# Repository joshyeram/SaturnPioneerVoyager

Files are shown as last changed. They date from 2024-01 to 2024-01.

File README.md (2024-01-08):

# Saturn with Pioneer and Voyager

link to the build video: https://www.youtube.com/watch?v=A1N8exJrTmQ

# Saturn
pioneer
With this keyboard, I wanted to experiment with the possibility of hot-swappable keyboards. In the current state of using machine sockets and pins, no one dares to hot-swap. And I wanted to fix that and come up with a universal microcontroller daughter board that you can simply swap around.

# Pioneer
pioneer
Pioneer is a simple daughterboard that supports a pro-micro-like microcontroller and a simple switch (reset). You can use qmk to program it.

# Voyager
voyager
Voyager is a complicated daughterboard that supports a pro-micro-like microcontroller, either oled or nice!view, a battery, and two switches (reset and power). Because of this, it is very thick to support all the hardware. In this case, I decided to use a Supermini for cost reasons. However, a genuine nice!nano should work as well. For programming, zmk was used for Bluetooth. 

# PCB
pcb
All you need is one pcb for all the boards. This is because I designed the daughter boards to be in the corners of the board to save manufacturing costs. This is at the cost of needing to score and snap off each board.
pcb
pcb
The reason why this works is because all the connections are standardized
pcb
Also, I think I got really lucky with the auditor not checking the thin mouse bite. so you may need to increase the tab if they do not except it.

# Firmware
I have already compiled and posted the .hex (qmk) and build.yaml(zmk) in the firmware folder. However, if you would like to make it your own, I have posted the full source code of what I used as well. (There may be some refactoring issues but I think I got most of them. Let me know if there is anything to fix)

# Parts
The most important part of the whole build was the DB25 connectors. I had to edit the existing DB25 footprint to fit my DB25 pins. So, you might have to as well.
Here is the list of parts I used
- pcb
- db25 connectors from amazon
- promicro 
- nice!nano clone
- nice!view from typeractive.xyz (they are great btw)
-  holy panda clones
- silent honey peaches
- 3 pin switches
- 1n4148 diodes
- uv resin
- some wire for cs pin
- keycaps (cerakeys w)

# anything else
please ask me anything if you guys want to! it is joshyeram on most platforms.

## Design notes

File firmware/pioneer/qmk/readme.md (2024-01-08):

# keyboard/pioneer

keyboard/pioneer

*A short description of the keyboard/project*

* Keyboard Maintainer: [joshyeram](https://github.com/joshyeram)
* Hardware Supported: *The PCBs, controllers supported*
* Hardware Availability: *Links to where you can find this hardware*

Make example for this keyboard (after setting up your build environment):

    make keyboard/pioneer:default

Flashing example for this keyboard:

    make keyboard/pioneer:default:flash

See the [build environment setup](https://docs.qmk.fm/#/getting_started_build_tools) and the [make instructions](https://docs.qmk.fm/#/getting_started_make_guide) for more information. Brand new to QMK? Start with our [Complete Newbs Guide](https://docs.qmk.fm/#/newbs).

## Bootloader

Enter the bootloader in 3 ways:

* **Bootmagic reset**: Hold down the key at (0,0) in the matrix (usually the top left key or Escape) and plug in the keyboard
* **Physical reset button**: Briefly press the button on the back of the PCB - some may have pads you must short instead
* **Keycode in layout**: Press the key mapped to `QK_BOOT` if it is available

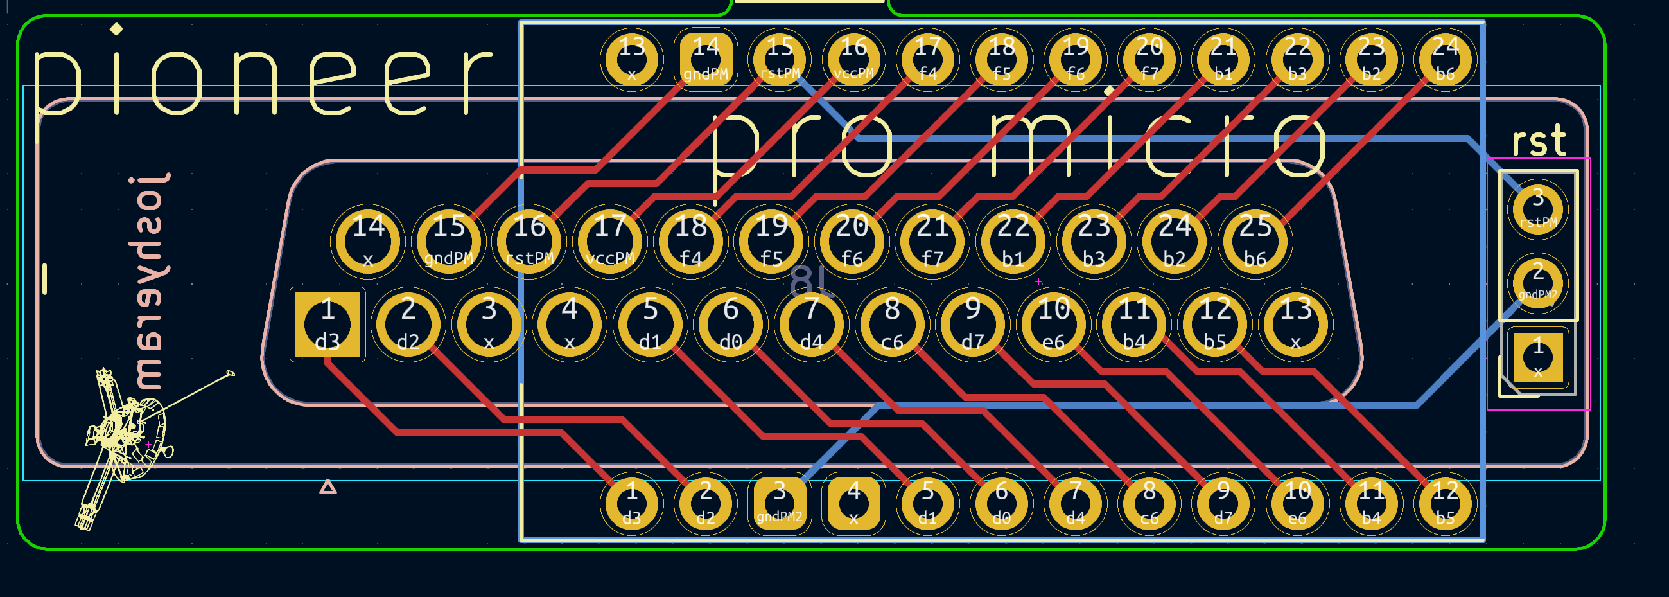
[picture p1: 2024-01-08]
overviewPngs/pioneerQuickOverview.PNG

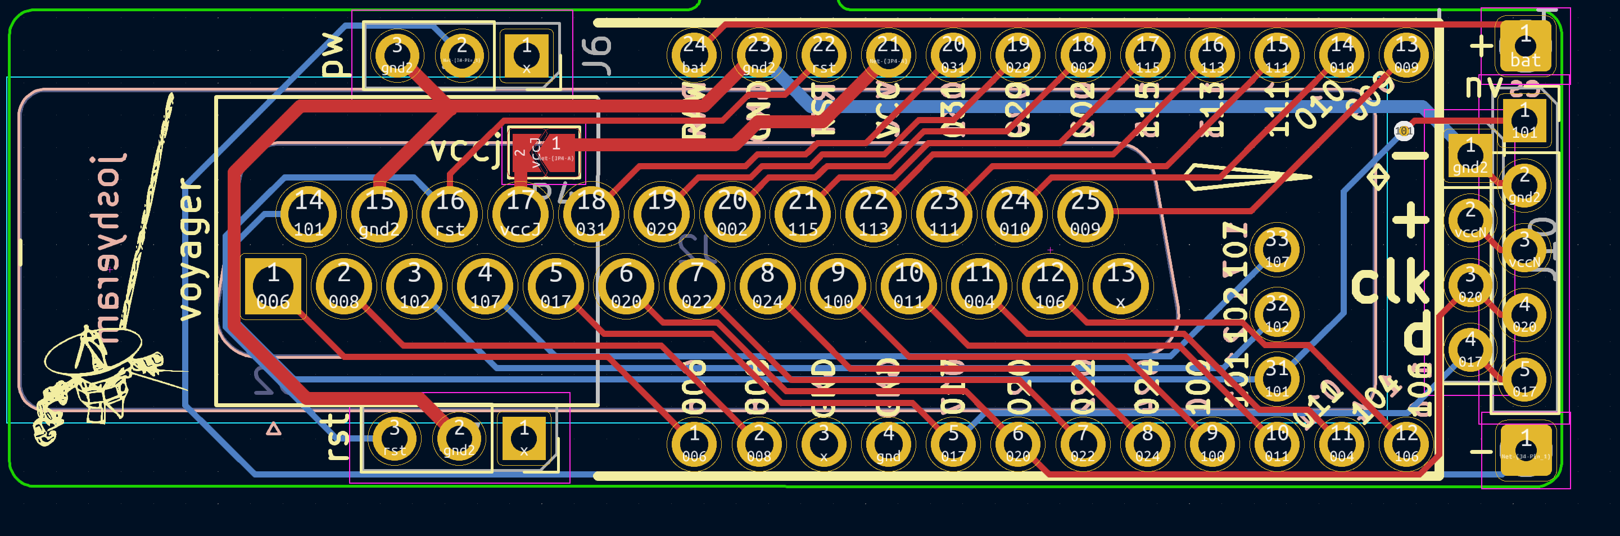
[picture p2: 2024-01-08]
overviewPngs/voyagerQuickOverview.PNG

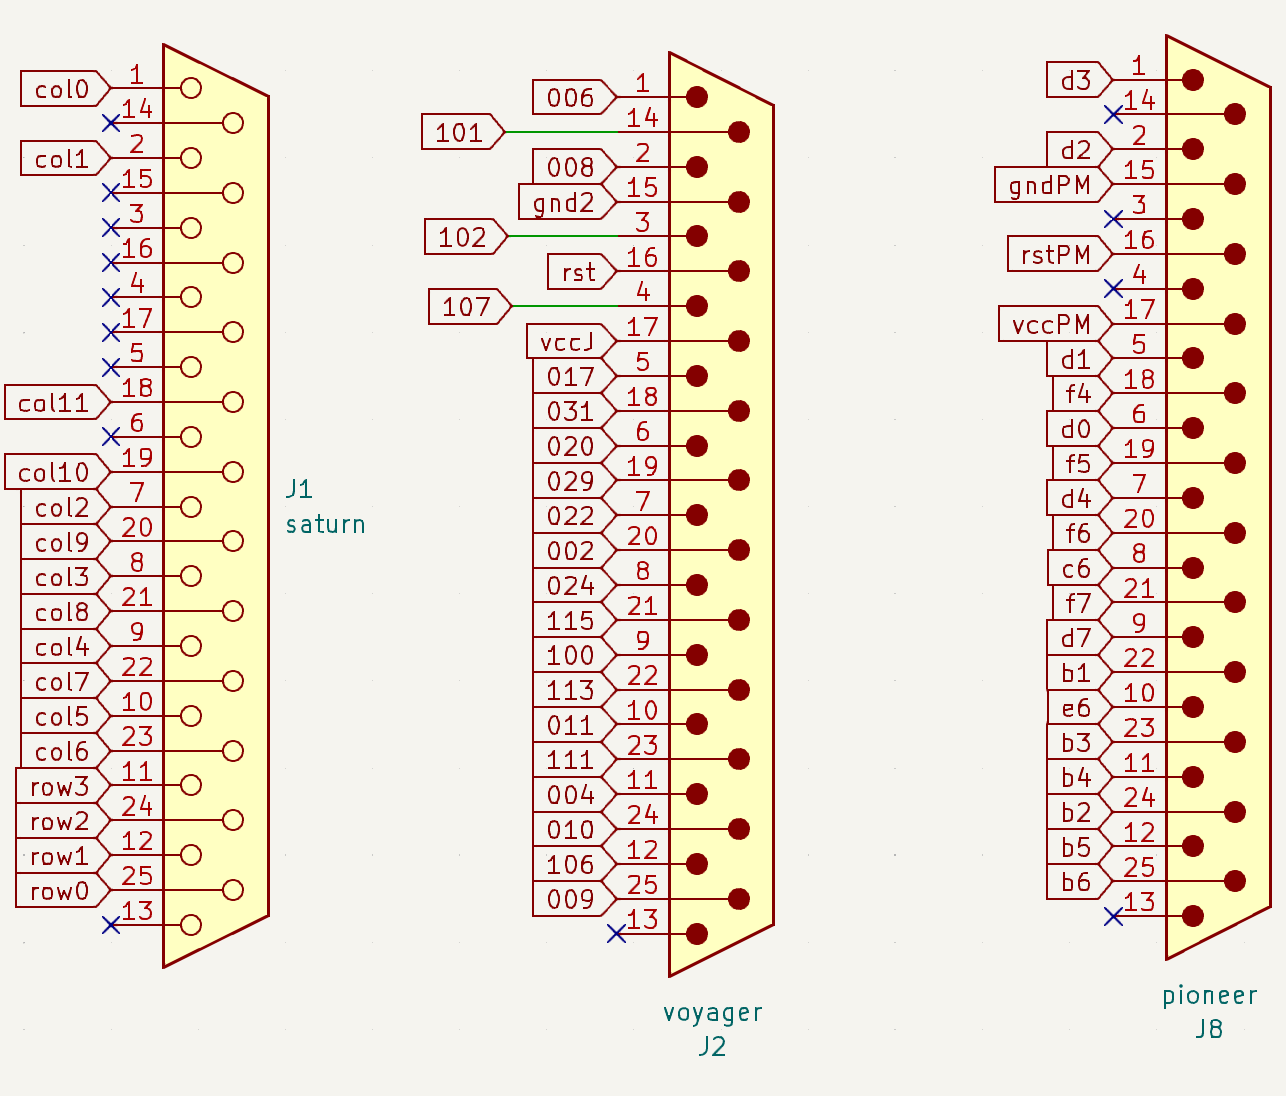
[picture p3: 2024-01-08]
overviewPngs/DsubConnectionsQuickOverview.PNG

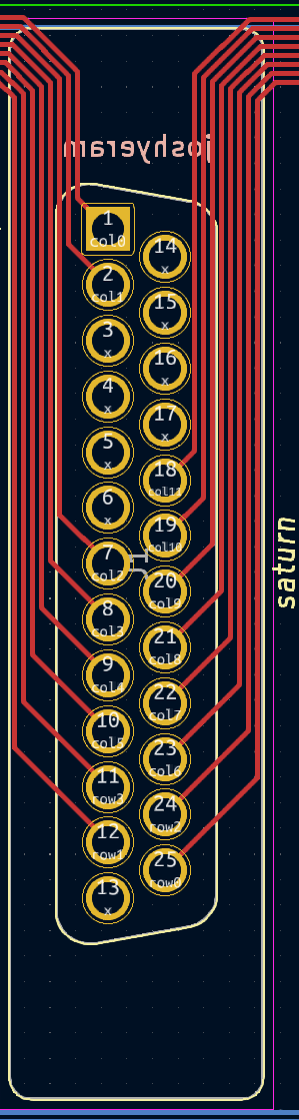
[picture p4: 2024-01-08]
overviewPngs/saturnQuickOverview.PNG

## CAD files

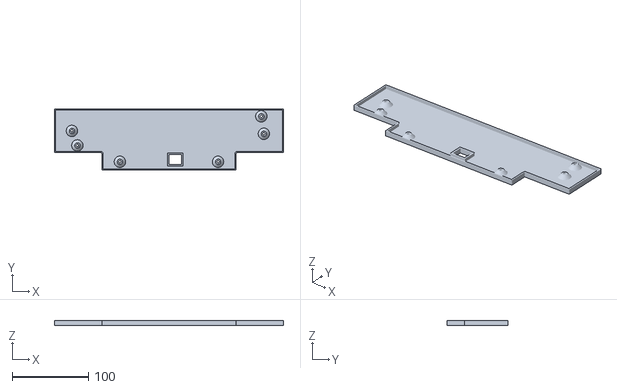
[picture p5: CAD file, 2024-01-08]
stls/whole.stl
300.0 x 80.3 x 6.00

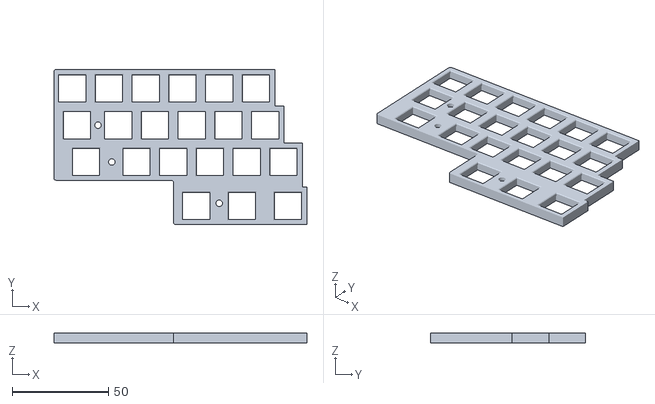
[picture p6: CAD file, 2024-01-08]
stls/leftTop.stl
131.2 x 80.3 x 5.00

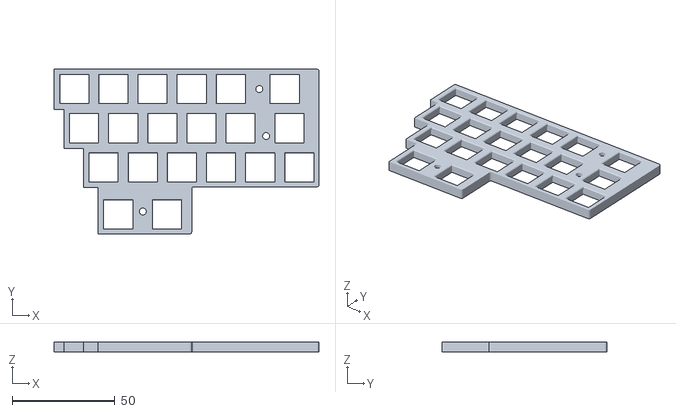
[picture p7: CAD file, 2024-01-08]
stls/rightTop.stl
128.9 x 80.2 x 5.00

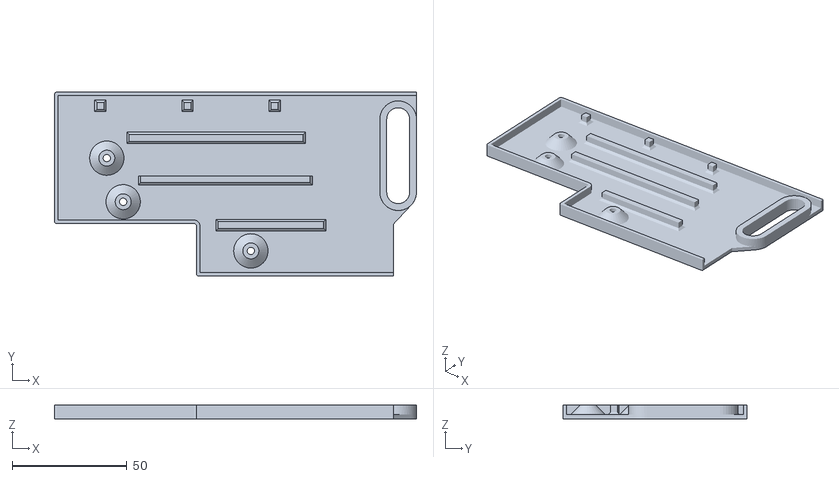
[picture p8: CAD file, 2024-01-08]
stls/leftBottom.stl
158.0 x 80.3 x 6.00

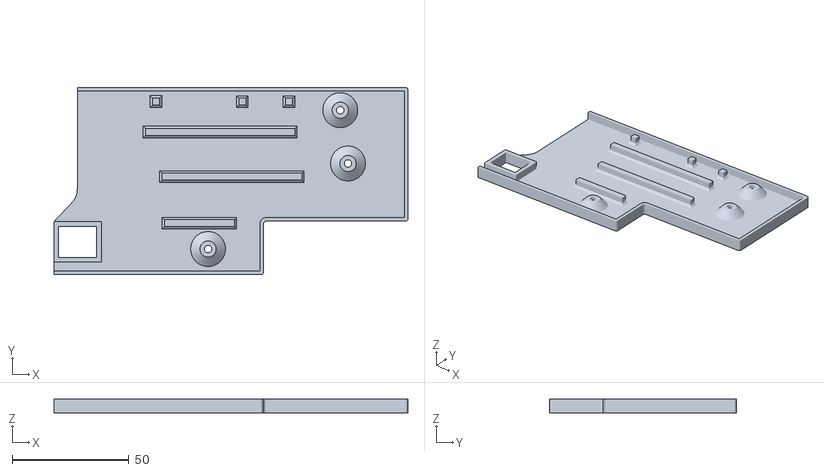
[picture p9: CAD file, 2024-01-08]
stls/rightBottom.stl
151.8 x 80.2 x 6.00

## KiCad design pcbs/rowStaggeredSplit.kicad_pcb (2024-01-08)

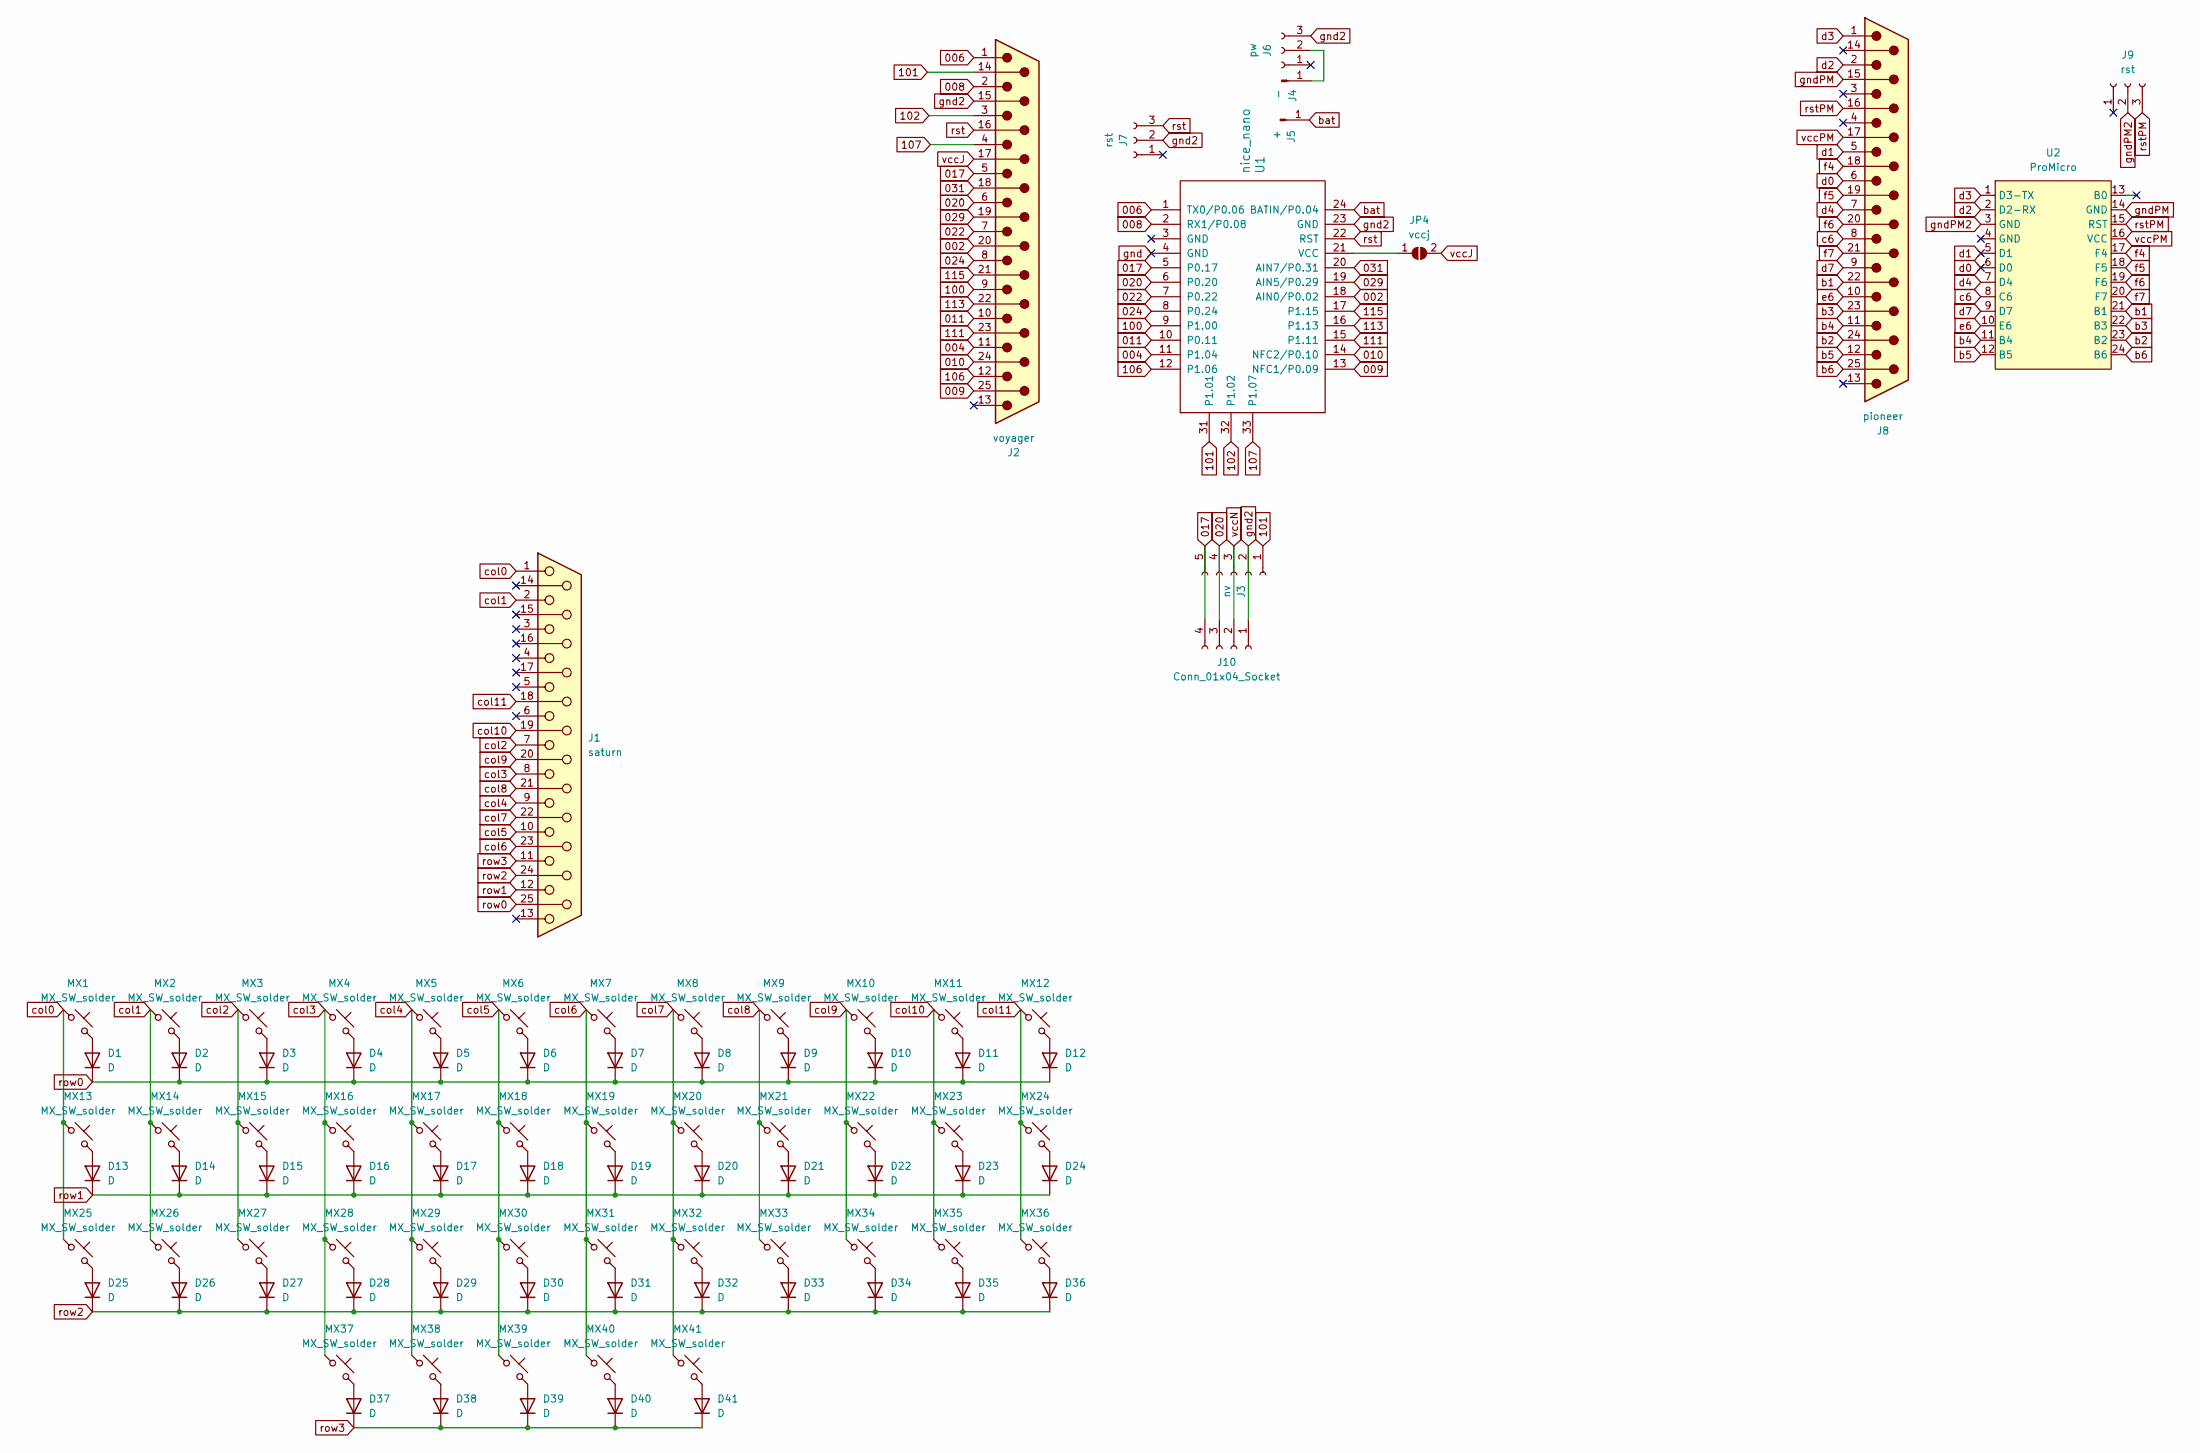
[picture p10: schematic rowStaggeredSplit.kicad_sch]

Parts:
D1, D2, D3, D4, D5, D6, D7, D8, D9, D10, D11, D12, D13, D14, D15, D16, D17, D18, D19, D20, D21, D22, D23, D24, D25, D26, D27, D28, D29, D30, D31, D32, D33, D34, D35, D36, D37, D38, D39, D40, D41: D; D_DO-35_SOD27_P7.62mm_Horizontal
J1: saturn; DSUB-25_Female_Vertical_P2.77x2.84mm2
J2: voyager; DSUB-25_Male_Vertical_P2.77x2.84mm2
J3: nv; PinSocket_1x05_P2.54mm_Vertical
J4: -; SolderWire-0.25sqmm_1x01_D0.65mm_OD2mm
J5: +; SolderWire-0.25sqmm_1x01_D0.65mm_OD2mm
J6: pw; PinSocket_1x03_P2.54mm_Vertical
J7, J9: rst; PinSocket_1x03_P2.54mm_Vertical
J8: pioneer; DSUB-25_Male_Vertical_P2.77x2.84mm2
J10: Conn_01x04_Socket; PinSocket_1x04_P2.54mm_Vertical
JP4: vccj; SolderJumper-2_P1.3mm_Open_TrianglePad1.0x1.5mm
MX1, MX2, MX3, MX4, MX5, MX6, MX7, MX8, MX9, MX10, MX11, MX14, MX15, MX16, MX17, MX18, MX19, MX20, MX21, MX22, MX23, MX26, MX27, MX28, MX29, MX30, MX31, MX32, MX33, MX34, MX35, MX36: MX_SW_solder; CherryMX_ChocV2_1u
MX12, MX25: MX_SW_solder; CherryMX_ChocV2_1.75u
MX13, MX37, MX38, MX39, MX40, MX41: MX_SW_solder; CherryMX_ChocV2_1.25u
MX24: MX_SW_solder; CherryMX_ChocV2_1.5u
U1: nice_nano
U2: ProMicro; ProMicro_USBup

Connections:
002: J2.20, U1.18 (AIN0/P0.02)
004: J2.11, U1.11 (P1.04)
006: J2.1, U1.1 (TX0/P0.06)
008: J2.2, U1.2 (RX1/P0.08)
009: J2.25, U1.13 (NFC1/P0.09)
010: J2.24, U1.14 (NFC2/P0.10)
011: J2.10, U1.10 (P0.11)
017: J2.5, J3.5, J10.4, U1.5 (P0.17)
020: J2.6, J3.4, J10.3, U1.6 (P0.20)
022: J2.7, U1.7 (P0.22)
024: J2.8, U1.8 (P0.24)
029: J2.19, U1.19 (AIN5/P0.29)
031: J2.18, U1.20 (AIN7/P0.31)
100: J2.9, U1.9 (P1.00)
101: J2.14, J3.1, U1.31 (P1.01)
102: J2.3, U1.32 (P1.02)
106: J2.12, U1.12 (P1.06)
107: J2.4, U1.33 (P1.07)
111: J2.23, U1.15 (P1.11)
113: J2.22, U1.16 (P1.13)
115: J2.21, U1.17 (P1.15)
unnamed: D1.2 (A), MX1.2
unnamed: D2.2 (A), MX2.2
unnamed: D3.2 (A), MX3.2
unnamed: D4.2 (A), MX4.2
unnamed: D5.2 (A), MX5.2
unnamed: D6.2 (A), MX6.2
unnamed: D7.2 (A), MX7.2
unnamed: D8.2 (A), MX8.2
unnamed: D9.2 (A), MX9.2
unnamed: D10.2 (A), MX10.2
unnamed: D11.2 (A), MX11.2
unnamed: D12.2 (A), MX12.2
unnamed: D13.2 (A), MX13.2
unnamed: D14.2 (A), MX14.2
unnamed: D15.2 (A), MX15.2
unnamed: D16.2 (A), MX16.2
unnamed: D17.2 (A), MX17.2
unnamed: D18.2 (A), MX18.2
unnamed: D19.2 (A), MX19.2
unnamed: D20.2 (A), MX20.2
unnamed: D21.2 (A), MX21.2
unnamed: D22.2 (A), MX22.2
unnamed: D23.2 (A), MX23.2
unnamed: D24.2 (A), MX24.2
unnamed: D25.2 (A), MX25.2
unnamed: D26.2 (A), MX26.2
unnamed: D27.2 (A), MX27.2
unnamed: D28.2 (A), MX28.2
unnamed: D29.2 (A), MX29.2
unnamed: D30.2 (A), MX30.2
unnamed: D31.2 (A), MX31.2
unnamed: D32.2 (A), MX32.2
unnamed: D33.2 (A), MX33.2
unnamed: D34.2 (A), MX34.2
unnamed: D35.2 (A), MX35.2
unnamed: D36.2 (A), MX36.2
unnamed: D37.2 (A), MX37.2
unnamed: D38.2 (A), MX38.2
unnamed: D39.2 (A), MX39.2
unnamed: D40.2 (A), MX40.2
unnamed: D41.2 (A), MX41.2
unnamed: J4.1, J6.2
unnamed: JP4.1 (A), U1.21 (VCC)
b1: J8.22, U2.21 (B1); also elsewhere on the board
b2: J8.24, U2.23 (B2); also elsewhere on the board
b3: J8.23, U2.22 (B3); also elsewhere on the board
b4: J8.11, U2.11 (B4); also elsewhere on the board
b5: J8.12, U2.12 (B5); also elsewhere on the board
b6: J8.25, U2.24 (B6); also elsewhere on the board
bat: J5.1, U1.24 (BATIN/P0.04)
c6: J8.8, U2.8 (C6); also elsewhere on the board
col0: J1.1, MX1.1, MX13.1, MX25.1
col1: J1.2, MX2.1, MX14.1, MX26.1
col2: J1.7, MX3.1, MX15.1, MX27.1
col3: J1.8, MX4.1, MX16.1, MX28.1, MX37.1
col4: J1.9, MX5.1, MX17.1, MX29.1, MX38.1
col5: J1.10, MX6.1, MX18.1, MX30.1, MX39.1
col6: J1.23, MX7.1, MX19.1, MX31.1, MX40.1
col7: J1.22, MX8.1, MX20.1, MX32.1, MX41.1
col8: J1.21, MX9.1, MX21.1, MX33.1
col9: J1.20, MX10.1, MX22.1, MX34.1
col10: J1.19, MX11.1, MX23.1, MX35.1
col11: J1.18, MX12.1, MX24.1, MX36.1
d0: J8.6, U2.6 (D0); also elsewhere on the board
d1: J8.5, U2.5 (D1); also elsewhere on the board
d2: J8.2, U2.2 (D2-RX); also elsewhere on the board
d3: J8.1, U2.1 (D3-TX); also elsewhere on the board
d4: J8.7, U2.7 (D4); also elsewhere on the board
d7: J8.9, U2.9 (D7); also elsewhere on the board
e6: J8.10, U2.10 (E6); also elsewhere on the board
f4: J8.18, U2.17 (F4); also elsewhere on the board
f5: J8.19, U2.18 (F5); also elsewhere on the board
f6: J8.20, U2.19 (F6); also elsewhere on the board
f7: J8.21, U2.20 (F7); also elsewhere on the board
gnd: U1.4 (GND)
gnd2: J2.15, J3.2, J6.3, J7.2, J10.1, U1.23 (GND)
gndPM: J8.15, U2.14 (GND); also elsewhere on the board
gndPM2: J9.2, U2.3 (GND)
row0: D1.1 (K), D2.1 (K), D3.1 (K), D4.1 (K), D5.1 (K), D6.1 (K), D7.1 (K), D8.1 (K), D9.1 (K), D10.1 (K), D11.1 (K), D12.1 (K), J1.25
row1: D13.1 (K), D14.1 (K), D15.1 (K), D16.1 (K), D17.1 (K), D18.1 (K), D19.1 (K), D20.1 (K), D21.1 (K), D22.1 (K), D23.1 (K), D24.1 (K), J1.12
row2: D25.1 (K), D26.1 (K), D27.1 (K), D28.1 (K), D29.1 (K), D30.1 (K), D31.1 (K), D32.1 (K), D33.1 (K), D34.1 (K), D35.1 (K), D36.1 (K), J1.24
row3: D37.1 (K), D38.1 (K), D39.1 (K), D40.1 (K), D41.1 (K), J1.11
rst: J2.16, J7.3, U1.22 (RST)
rstPM: J8.16, J9.3, U2.15 (RST); also elsewhere on the board
vccJ: J2.17, JP4.2 (B)
vccN: J3.3, J10.2
vccPM: J8.17, U2.16 (VCC); also elsewhere on the board

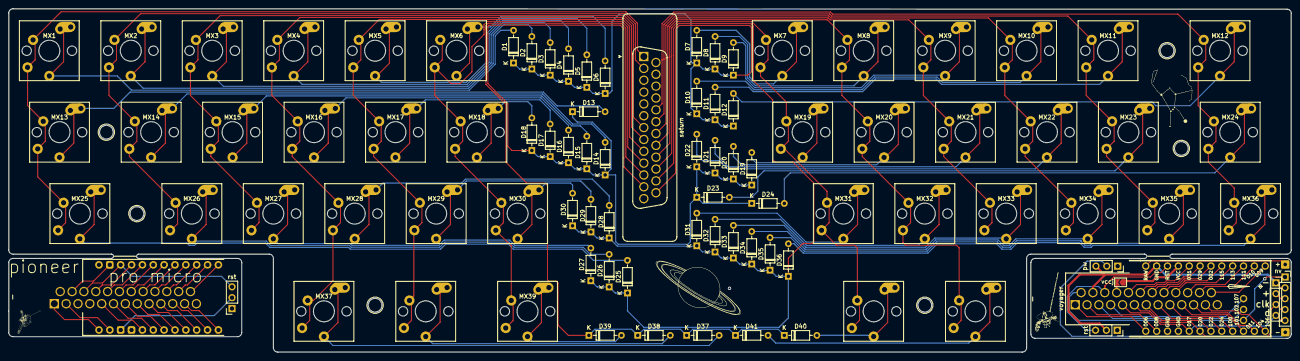
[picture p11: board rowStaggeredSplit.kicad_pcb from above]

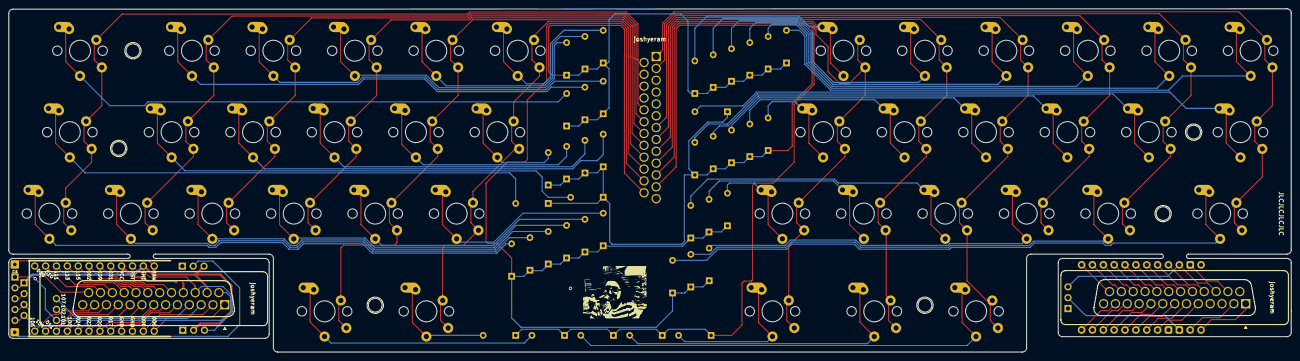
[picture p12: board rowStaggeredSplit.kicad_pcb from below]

Board: 2 copper layers, 300.0 x 80.3 mm, 96 parts (2 on the bottom side), 107 nets.

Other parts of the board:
Ge: LOGO; jor
locked: titan; DSUB-25_Male_Vertical_P2.77x2.84mm2

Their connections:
b1: locked.22; also elsewhere on the board
b2: locked.24; also elsewhere on the board
b3: locked.23; also elsewhere on the board
b4: locked.11; also elsewhere on the board
b5: locked.12; also elsewhere on the board
b6: locked.25; also elsewhere on the board
c6: locked.8; also elsewhere on the board
d0: locked.6; also elsewhere on the board
d1: locked.5; also elsewhere on the board
d2: locked.2; also elsewhere on the board
d3: locked.1; also elsewhere on the board
d4: locked.7; also elsewhere on the board
d7: locked.9; also elsewhere on the board
e6: locked.10; also elsewhere on the board
f4: locked.18; also elsewhere on the board
f5: locked.19; also elsewhere on the board
f6: locked.20; also elsewhere on the board
f7: locked.21; also elsewhere on the board
gndPM: locked.15; also elsewhere on the board
rstPM: locked.16; also elsewhere on the board
vccPM: locked.17; also elsewhere on the board

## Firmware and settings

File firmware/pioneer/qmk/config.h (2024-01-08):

// Copyright 2023 joshyeram (@joshyeram)
// SPDX-License-Identifier: GPL-2.0-or-later

#pragma once
#define MOUSEKEY_DELAY 0
#define MOUSEKEY_INTERVAL 16
#define MOUSEKEY_WHEEL_DELAY 0
#define MOUSEKEY_MAX_SPEED 3
#define MOUSEKEY_MOVE_DELTA 2
#define MOUSEKEY_TIME_TO_MAX 64
#define TAPPING_TERM 800
/*
 * Feature disable options
 *  These options are also useful to firmware size reduction.
 */

/* disable debug print */
//#define NO_DEBUG

/* disable print */
//#define NO_PRINT

/* disable action features */
//#define NO_ACTION_LAYER
//#define NO_ACTION_TAPPING
//#define NO_ACTION_ONESHOT
